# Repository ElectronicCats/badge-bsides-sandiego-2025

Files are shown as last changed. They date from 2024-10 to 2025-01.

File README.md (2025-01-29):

# Badge bsides San Diego 2025

## Technology

- CH32V003
- LEDs
- Display OLED
- 2x AAA Battery Holder
- Shitty Addon Connector

## Gratitude
Do you want to say thank you? Tag these companies on social networks and show them your badge, thanks to them it is possible

- [ElectronicCats](https://electroniccats.com/)
- [BsidesSanDiego](https://www.bsidessd.org/)

## License

Electronic Cats invests time and resources providing this open source design, please support Electronic Cats and open-source hardware by purchasing products from Electronic Cats!

Designed by Electronic Cats.

Hardware released under an CERN Open Hardware Licence v1.2. See the LICENSE_HARDWARE file for more information.

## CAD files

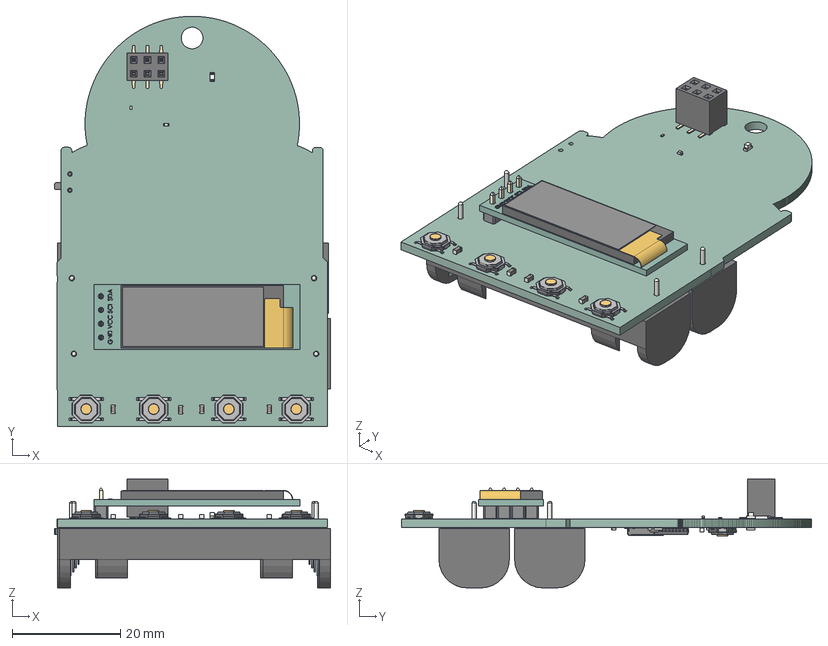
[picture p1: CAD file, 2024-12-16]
hardware/Bsides_sandiego_2025.step
50.9 x 75.7 x 20.1 mm
SW_SPST_TL3342 x 5
PinSocket_2x03_P254mm_Vertical_SMD
C_0603_1608Metric x 6
LED_0201_0603Metric
LED_0402_1005Metric
128x32-OLED v4
LED_0603_1608Metric
R_0603_1608Metric x 8
Keystone_2466_1xAAA x 2
TSSOP_20_44x65mm_P065mm
MSK12C02
_autosave-Bsides_sandiego_2025_PCB

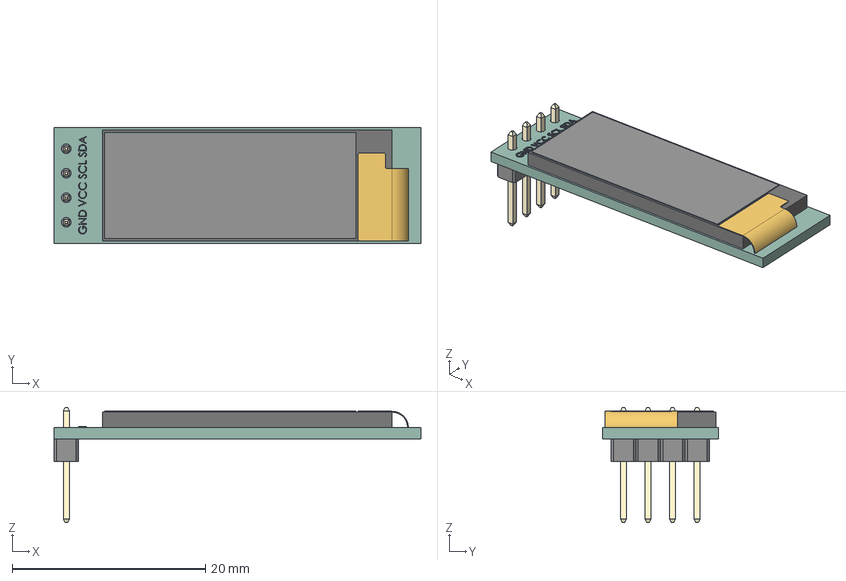
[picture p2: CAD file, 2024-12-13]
hardware/Footprints/3D/128x32-OLED.STEP
38.0 x 12.0 x 11.9 mm

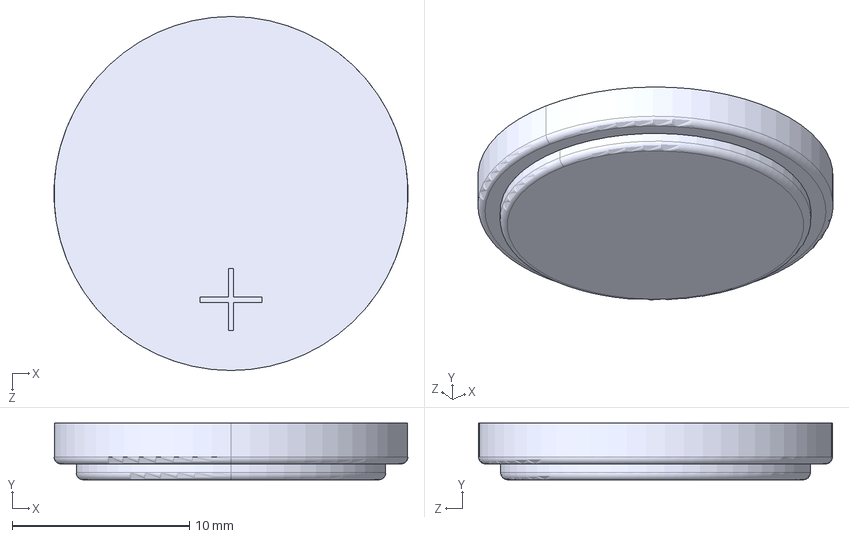
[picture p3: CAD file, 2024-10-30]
hardware/Footprints/3D/CR2032--3DModel-STEP-56544.STEP
20.0 x 3.20 x 20.0 mm

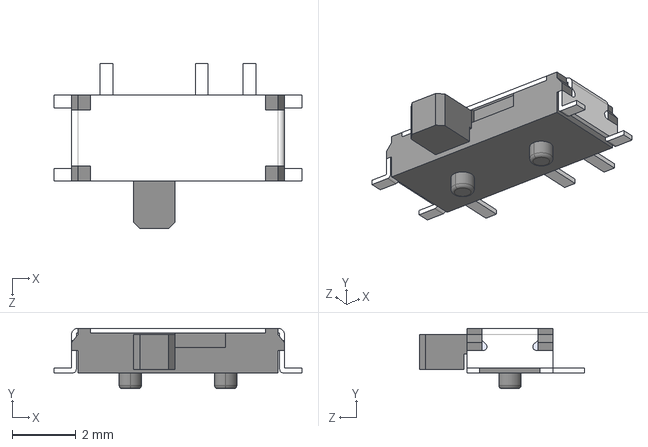
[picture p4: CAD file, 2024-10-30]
hardware/Footprints/3D/MSK12C02.stp
7.80 x 1.90 x 5.20 mm

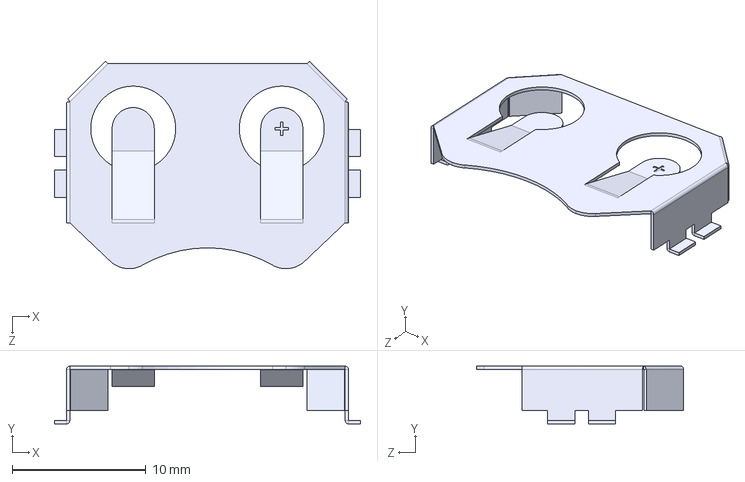
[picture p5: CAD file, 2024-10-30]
hardware/Footprints/3D/BAT-HLD-001--3DModel-STEP-56544.STEP
22.9 x 4.32 x 15.5 mm

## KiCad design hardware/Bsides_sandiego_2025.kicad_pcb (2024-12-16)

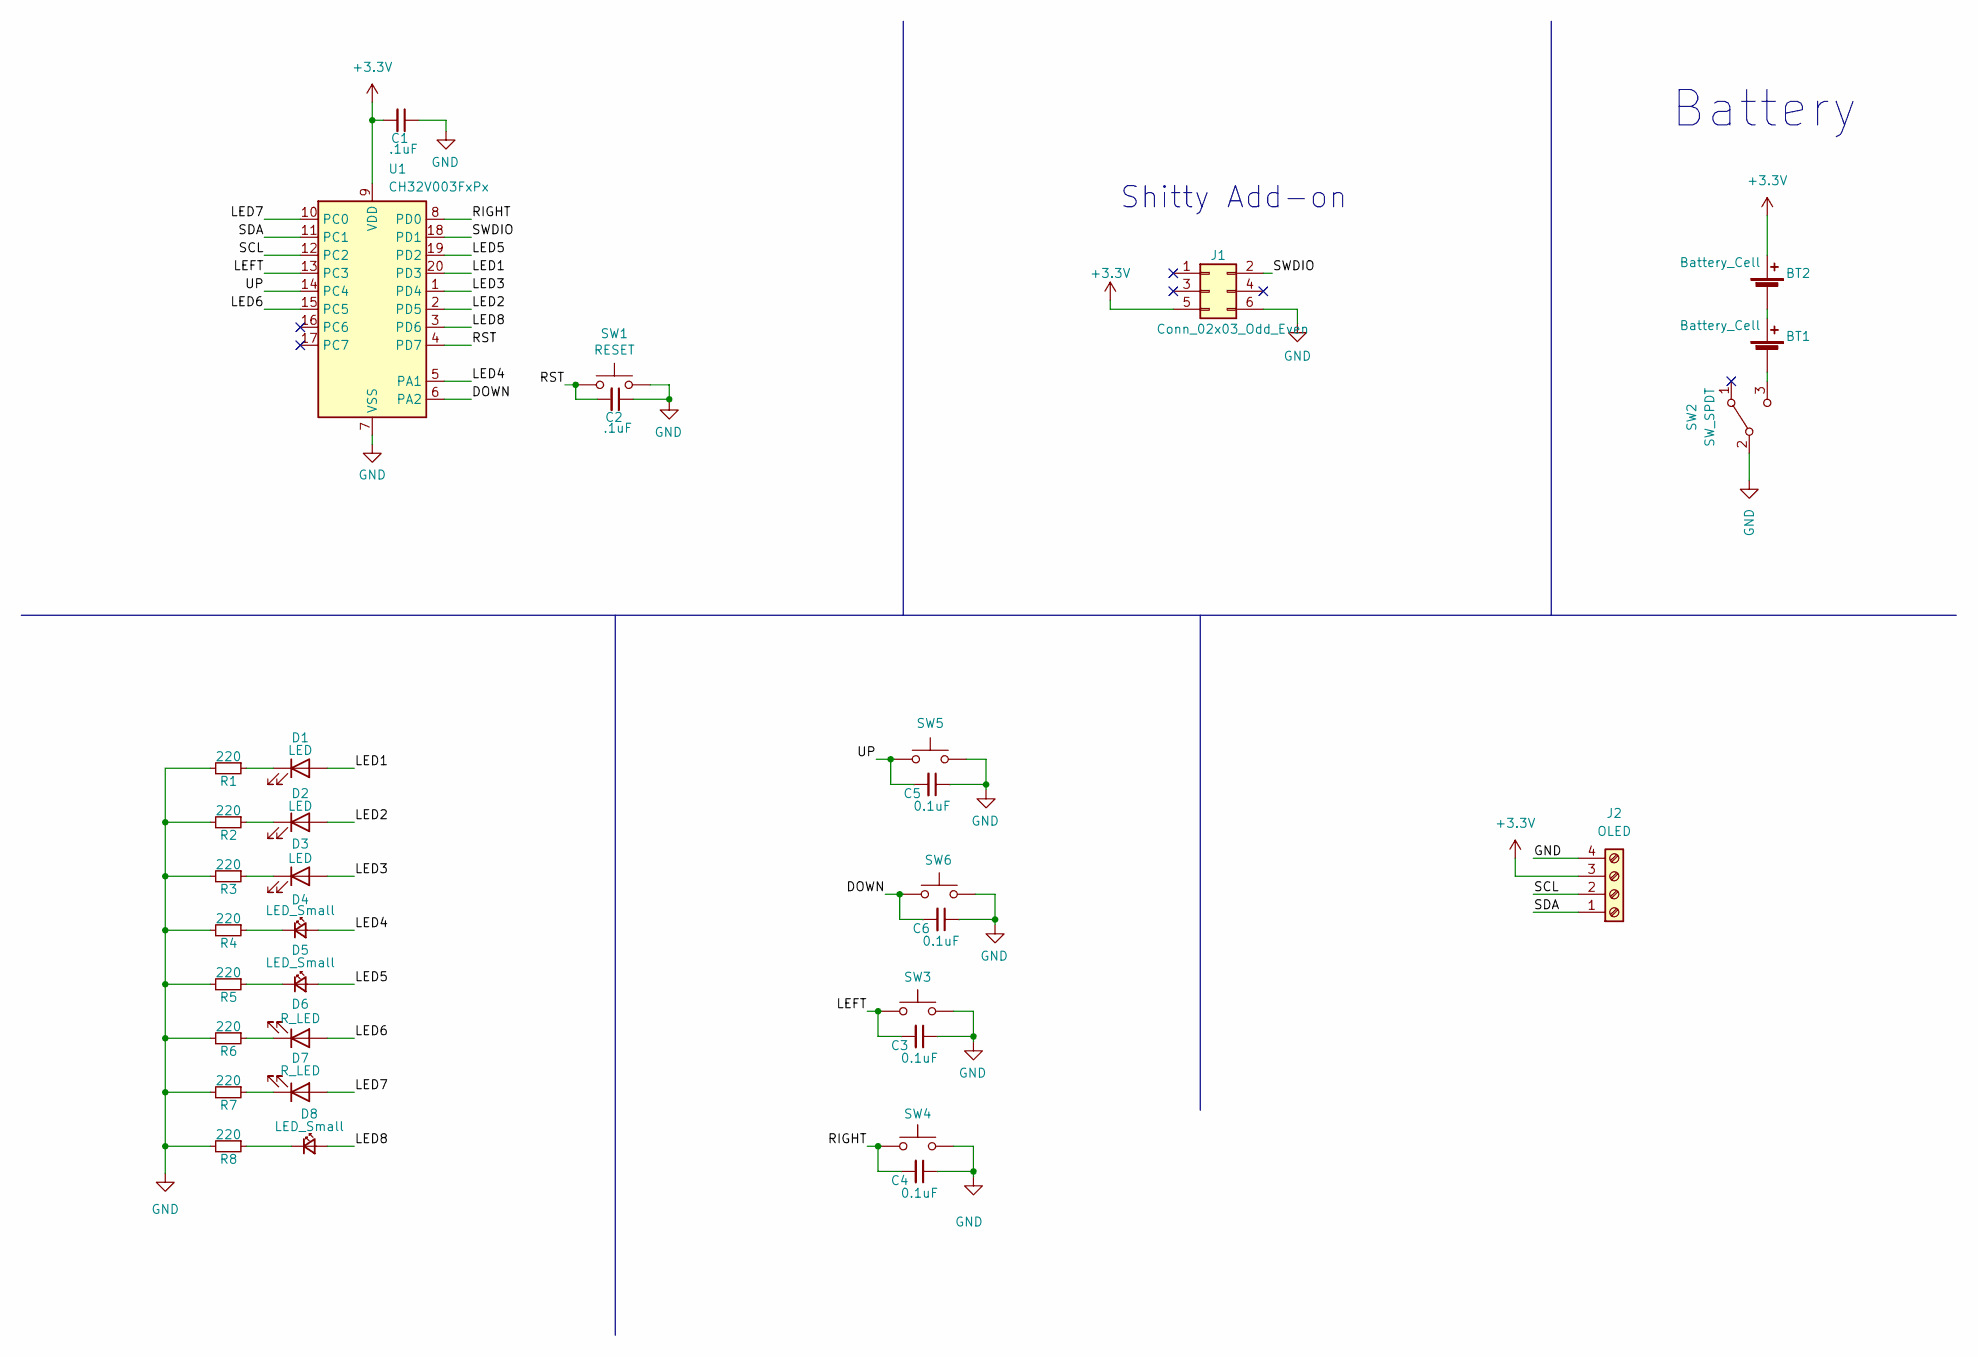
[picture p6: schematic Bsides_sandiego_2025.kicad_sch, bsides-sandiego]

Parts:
BT1, BT2: Battery_Cell; BatteryHolder_Keystone_2466_1xAAA; LCSC# C5290189
C1, C2: .1uF; C_0603_1608Metric; LCSC# C478888
C3, C4, C5, C6: 0.1uF; C_0603_1608Metric; LCSC# C478888
D1: LED; LED_0201_0603Metric; LCSC# C5440628
D2: LED; LED_0402_1005Metric; LCSC# C434450
D3: LED; LED_0603_1608Metric; LCSC# C434424
D4, D5: LED_Small; LED_S; LCSC# C2886268
D6, D7: R_LED; LYT77K-K2M1
D8: LED_Small; Led_S_S; LCSC# C409795
J1: Conn_02x03_Odd_Even; PinHeader_2x03_P2.54mm_Vertical_SMD; LCSC# C124390
J2: OLED; Display OLED 128 x32
R1, R2, R3, R4, R5, R6, R7, R8: 220; R_0603_1608Metric; LCSC# C22962
SW1: RESET; SW_SPST_TL3342; LCSC# C318889
SW2: SW_SPDT; MSK12C02; LCSC# C431540
SW3, SW4, SW5, SW6: SW_SPST_TL3342; LCSC# C318889
U1: CH32V003FxPx; TSSOP-20_4.4x6.5mm_P0.65mm; LCSC# C5187096

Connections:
+3.3V: BT2.2 (+), C1.2, J1.5, J2.3, U1.9 (VDD)
/DOWN: C6.2, SW6.2, U1.6 (PA2)
/LED1: D1.2 (A), U1.20 (PD3)
/LED2: D2.2 (A), U1.2 (PD5)
/LED3: D3.2 (A), U1.1 (PD4)
/LED4: D4.2 (A), U1.5 (PA1)
/LED5: D5.2 (A), U1.19 (PD2)
/LED6: D6.2 (A), U1.15 (PC5)
/LED7: D7.2 (A), U1.10 (PC0)
/LED8: D8.2 (A), U1.3 (PD6)
/LEFT: C3.2, SW3.2, U1.13 (PC3)
/RIGHT: C4.2, SW4.2, U1.8 (PD0)
/RST: C2.2, SW1.2, U1.4 (PD7)
/SCL: J2.2, U1.12 (PC2)
/SDA: J2.1, U1.11 (PC1)
/SWDIO: J1.2, U1.18 (PD1)
/UP: C5.2, SW5.2, U1.14 (PC4)
GND: C1.1, C2.1, C3.1, C4.1, C5.1, C6.1, J1.6, J2.4, R1.2, R2.2, R3.2, R4.2, R5.2, R6.2, R7.2, R8.2, SW1.1, SW2.2 (B), SW3.1, SW4.1, SW5.1, SW6.1, U1.7 (VSS)
unnamed: BT1.2 (+), BT2.1 (-)
unnamed: BT1.1 (-), SW2.3 (C)
unnamed: D1.1 (K), R1.1
unnamed: D2.1 (K), R2.1
unnamed: D3.1 (K), R3.1
unnamed: D4.1 (K), R4.1
unnamed: D5.1 (K), R5.1
unnamed: D6.1 (K), R6.1
unnamed: D7.1 (K), R7.1
unnamed: D8.1 (K), R8.1

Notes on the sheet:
Shitty Add-on
Battery

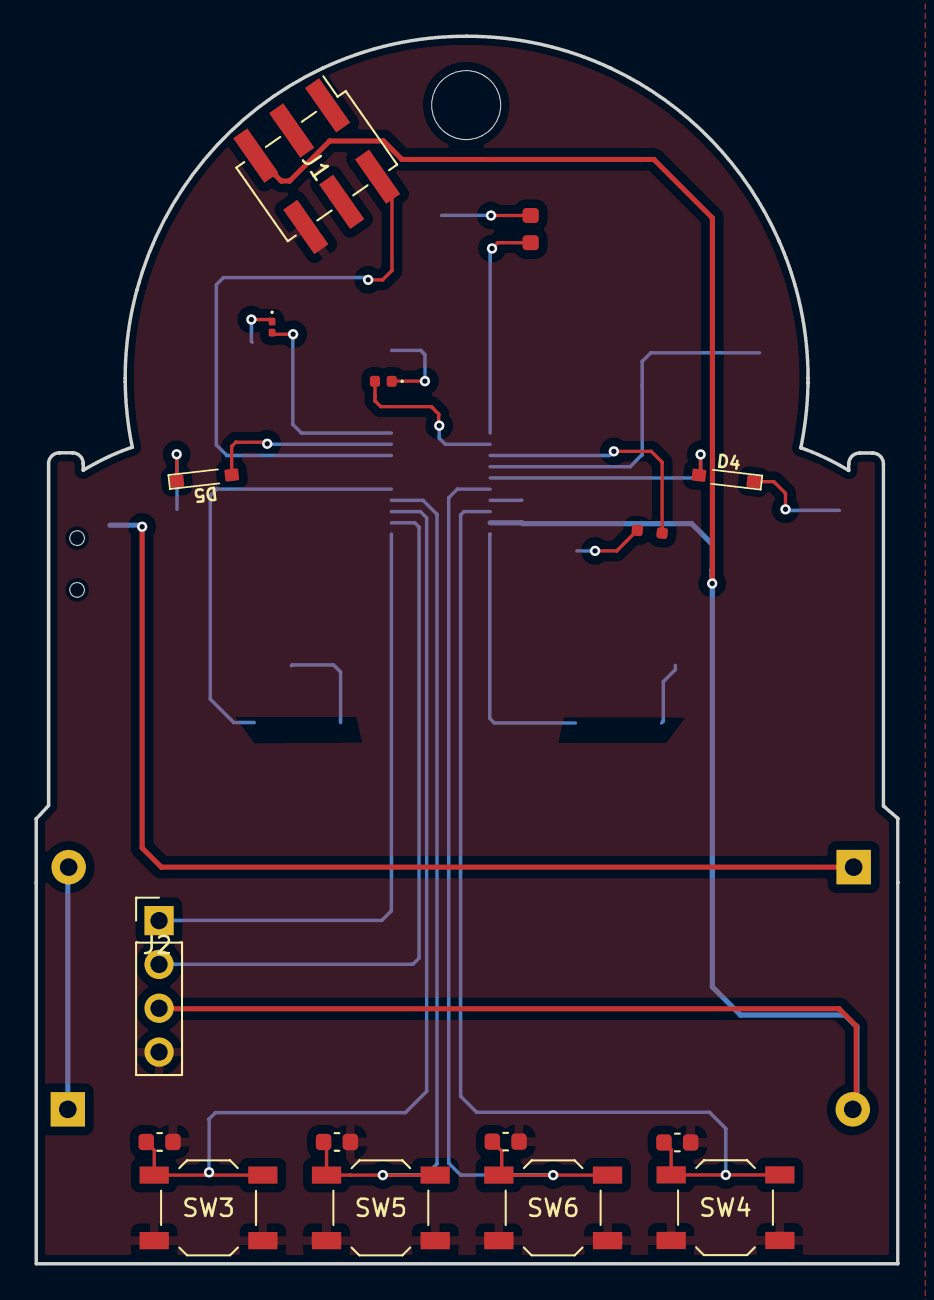
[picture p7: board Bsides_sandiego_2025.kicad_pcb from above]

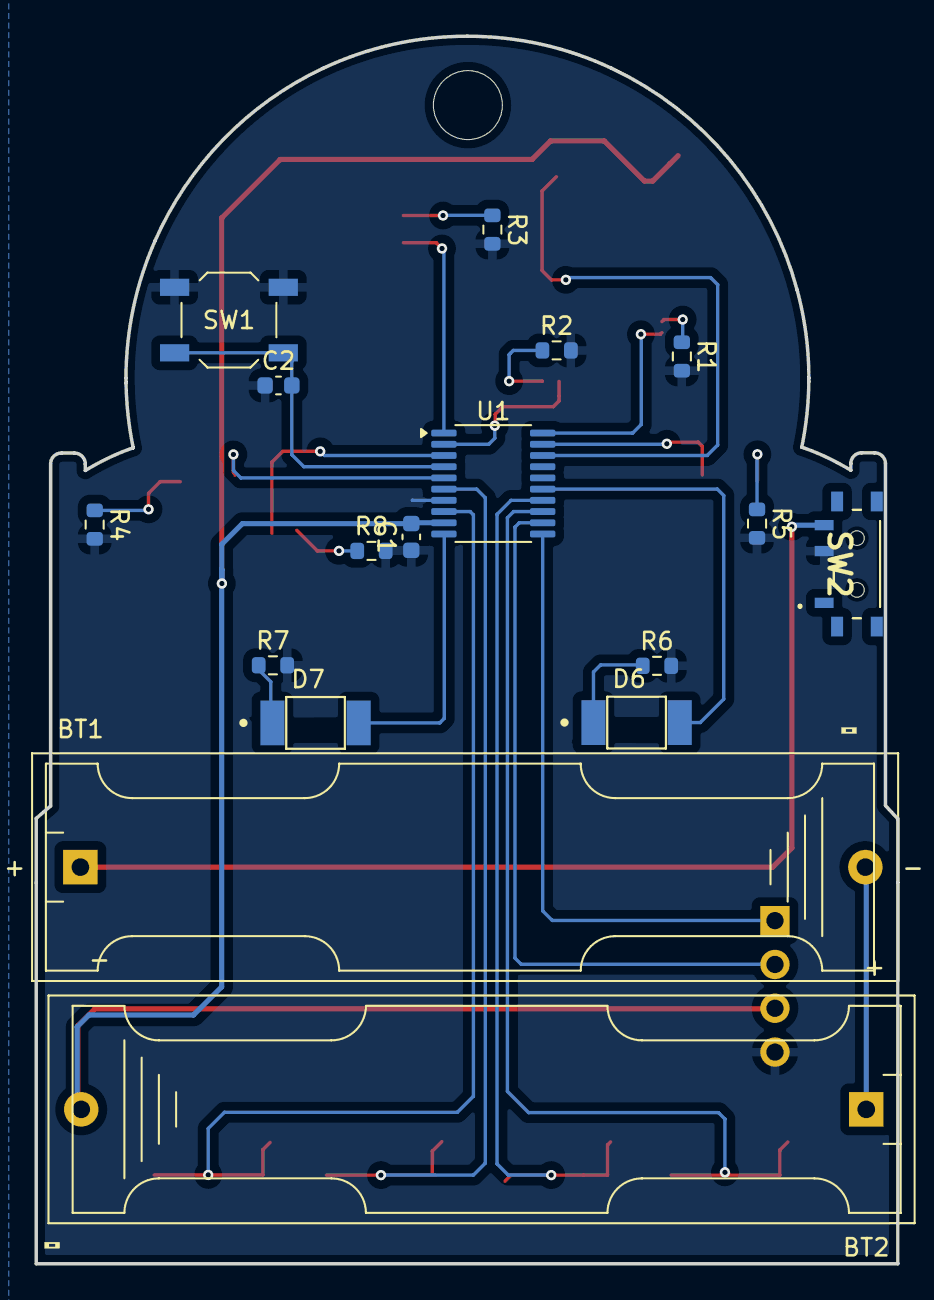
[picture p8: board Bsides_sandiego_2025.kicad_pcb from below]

Board: 2 copper layers, 49.9 x 71.2 mm, 36 parts (19 on the bottom side), 28 nets.

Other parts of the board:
Ref**: Val**; BAGDE BSIDES SAN DIEGO 25_30-10-24
kibuzzard-67607E30, kibuzzard-67607E30#2: G***; kibuzzard-67607E30

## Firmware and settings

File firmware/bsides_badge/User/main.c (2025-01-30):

/********************************** (C) COPYRIGHT
 ******************************** File Name          : main.c Author : WCH
 * Version            : V1.0.0
 * Date               : 2023/12/25
 * Description        : Main program body.
 *********************************************************************************
 * Copyright (c) 2021 Nanjing Qinheng Microelectronics Co., Ltd.
 * Attention: This software (modified or not) and binary are used for
 * microcontroller manufactured by Nanjing Qinheng Microelectronics.
 *******************************************************************************/

/*
 *@Note
 *Multiprocessor communication mode routine:
 *Master:USART1_Tx(PD5)\USART1_Rx(PD6).
 *This routine demonstrates that USART1 receives the data sent by CH341 and
 *inverts it and sends it (baud rate 115200).
 *
 *Hardware connection:PD5 -- Rx
 *                     PD6 -- Tx
 *
 */

#include <limits.h>
#include "../SSD1306/include/ssd1306.h"
#include "bitmaps.h"
#include "debug.h"
#include "driver.h"
#include "hardware_tests.h"
#include "menus.h"
#include "tetris.h"

uint16_t valueInFlash;

void USARTx_CFG(void);

int main() {
  SystemCoreClockUpdate();
  Delay_Init();
#if (SDI_PRINT == SDI_PR_OPEN)
  SDI_Printf_Enable();
#else
  USART_Printf_Init(115200);
#endif

  // Setup
  // USARTx_CFG();
  JOY_init();
  ssd1306_setbuf(0);
  ssd1306_refresh();
  ssd1306_drawImage(epd_bitmap_bsides_logo, 0, 0, 128, 32, COLOR_NORMAL);
  ssd1306_refresh();

  // Blink all the LEDs
  uint8_t delay = 50;
  for (uint8_t i = 0; i < leds_count; i++) {
    PIN_high(leds[i]);
    JOY_DLY_ms(delay);
    PIN_low(leds[i]);
    JOY_DLY_ms(delay);
  }
  Delay_Ms(500);  // Keep the logo on the screen for a while
  // flash_test();
  // hardware_tests_start();
  menus_init();
  // tetris_start();
}

/*********************************************************************
 * @fn      USARTx_CFG
 *
 * @brief   Initializes the USART2 & USART3 peripheral.
 *
 * @return  none
 */
void USARTx_CFG(void) {
  GPIO_InitTypeDef GPIO_InitStructure = {0};
  USART_InitTypeDef USART_InitStructure = {0};

  RCC_APB2PeriphClockCmd(RCC_APB2Periph_GPIOD | RCC_APB2Periph_USART1, ENABLE);

  /* USART1 TX-->D.5   RX-->D.6 */
  GPIO_InitStructure.GPIO_Pin = GPIO_Pin_5;
  GPIO_InitStructure.GPIO_Speed = GPIO_Speed_30MHz;
  GPIO_InitStructure.GPIO_Mode = GPIO_Mode_AF_PP;
  GPIO_Init(GPIOD, &GPIO_InitStructure);
  GPIO_InitStructure.GPIO_Pin = GPIO_Pin_6;
  GPIO_InitStructure.GPIO_Mode = GPIO_Mode_IN_FLOATING;
  GPIO_Init(GPIOD, &GPIO_InitStructure);

  USART_InitStructure.USART_BaudRate = 115200;
  USART_InitStructure.USART_WordLength = USART_WordLength_8b;
  USART_InitStructure.USART_StopBits = USART_StopBits_1;
  USART_InitStructure.USART_Parity = USART_Parity_No;
  USART_InitStructure.USART_HardwareFlowControl =
      USART_HardwareFlowControl_None;
  USART_InitStructure.USART_Mode = USART_Mode_Tx | USART_Mode_Rx;

  USART_Init(USART1, &USART_InitStructure);
  USART_Cmd(USART1, ENABLE);
}

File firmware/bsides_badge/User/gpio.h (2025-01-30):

// ===================================================================================
// Basic GPIO Functions for CH32V003                                          * v1.6 *
// ===================================================================================
//
// Pins must be defined as PA0, PA1, .., PC0, PC1, etc. - e.g.:
// #define PIN_LED PC0      // LED on pin PC0
//
// PIN functions available:
// ------------------------
// PIN_input(PIN)           Set PIN as INPUT (floating, no pullup/pulldown)
// PIN_input_PU(PIN)        Set PIN as INPUT with internal PULLUP resistor
// PIN_input_PD(PIN)        Set PIN as INPUT with internal PULLDOWN resistor
// PIN_input_AN(PIN)        Set PIN as INPUT for analog peripherals (e.g. ADC) (*)
// PIN_output(PIN)          Set PIN as OUTPUT (push-pull)
// PIN_output_OD(PIN)       Set PIN as OUTPUT (open-drain)
// PIN_alternate(PIN)       Set PIN as alternate output (push-pull)
// PIN_alternate_OD(PIN)    Set PIN as alternate output (open-drain)
//
// PIN_low(PIN)             Set PIN output value to LOW (*)
// PIN_high(PIN)            Set PIN output value to HIGH
// PIN_toggle(PIN)          TOGGLE PIN output value
// PIN_read(PIN)            Read PIN input value
// PIN_write(PIN, val)      Write PIN output value (0 = LOW / 1 = HIGH)
//
// PIN interrupt and event functions available:
// --------------------------------------------
// PIN_EVT_set(PIN,TYPE)    Setup PIN event TYPE:
//                          PIN_EVT_OFF, PIN_EVT_RISING, PIN_EVT_FALLING, PIN_EVT_BOTH
// PIN_INT_set(PIN,TYPE)    Setup PIN interrupt TYPE:
//                          PIN_INT_OFF, PIN_INT_RISING, PIN_INT_FALLING, PIN_INT_BOTH
// PIN_INT_enable()         Enable PIN interrupts
// PIN_INT_disable()        Disable PIN interrupts
// PIN_INTFLAG_read(PIN)    Read interrupt flag of PIN
// PIN_INTFLAG_clear(PIN)   Clear interrupt flag of PIN
// PIN_INT_ISR { }          Pin interrupt service routine
//
// PORT functions available:
// -------------------------
// PORT_enable(PIN)         Enable GPIO PORT of PIN
// PORTA_enable()           Enable GPIO PORT A
// PORTC_enable()           Enable GPIO PORT C
// PORTD_enable()           Enable GPIO PORT D
// PORTS_enable()           Enable all GPIO PORTS
//
// PORT_disable(PIN)        Disable GPIO PORT of PIN
// PORTA_disable()          Disable GPIO PORT A
// PORTC_disable()          Disable GPIO PORT C
// PORTD_disable()          Disable GPIO PORT D
// PORTS_disable()          Disable all GPIO PORTS
//
// Analog-to-Digital Converter (ADC) functions available:
// ------------------------------------------------------
// ADC_init()               Init, enable and calibrate ADC (must be called first)
// ADC_enable()             Enable ADC (power-up)
// ADC_disable()            Disable ADC (power-down)
// ADC_calibrate()          Calibrate ADC
//
// ADC_fast()               Set fast mode   ( 28 clock cycles, least accurate) (*)
// ADC_medium()             Set medium mode (168 clock cycles, medium accurate)
// ADC_slow()               Set slow mode   (504 clock cycles, most accurate)
//
// ADC_input(PIN)           Set PIN as ADC input
// ADC_input_VREF()         Set internal voltage referece (Vref) as ADC input
// ADC_input_VCAL()         Set calibration voltage (Vcal) as ADC input
//
// ADC_read()               Sample and read ADC value (0..1023)
// ADC_read_VDD()           Sample and read supply voltage (VDD) in millivolts (mV)
//
// Op-Amp Comparator (OPA) functions available:
// --------------------------------------------
// OPA_enable()             Enable OPA comparator
// OPA_disable()            Disable OPA comparator
// OPA_negative(PIN)        Set OPA inverting input PIN (PA1, PD0 only)
// OPA_positive(PIN)        Set OPA non-inverting input PIN (PA2, PD7 only)
// OPA_output()             Enable OPA output (push-pull) on pin PD4
// OPA_output_OD()          Enable OPA output (open-drain) on pin PD4
// OPA_read()               Read OPA output (0: pos < neg, 1: pos > neg)
//
// Notes:
// ------
// - (*) default state
// - For interrupts and events: Each PIN number can only be used once simultaneously.
//   (For example, PA1 and PC1 cannot be used simultaneously, but PA1 and PC2).
// - Pins used for ADC must be set with PIN_input_AN beforehand. Only the following 
//   pins can be used as INPUT for the ADC: PA1, PA2, PC4, PD2, PD3, PD4, PD5, PD6.
// - Pins used as input for OPA comparator must be set with PIN_input_AN beforehand.
//   Only the following pins can be used for the OPA: PA1 or PD0 as negative
//   (inverting) input, PA2 or PD7 as positive (non-inverting) input and PD4 as
//   ouput.
//
// 2023 by Stefan Wagner:   https://github.com/wagiminator

#pragma once

#ifdef __cplusplus
extern "C" {
#endif
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

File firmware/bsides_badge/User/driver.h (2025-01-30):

// ===================================================================================
// Tiny Joypad Drivers for CH32V003                                           *
// v1.0 *
// ===================================================================================
//
// MCU abstraction layer.
// 2023 by Stefan Wagner:   https://github.com/wagiminator

#pragma once

#ifdef __cplusplus
extern "C" {
#endif

#include <stdbool.h>
#include "ch32v00x.h"
#include "gpio.h"
#include "oled_min.h"

// #define DEBUG_ENABLE 1
// #define DEV_VERSION 1

#define APP_DBG(X...)             \
  if (1) {                        \
    PRINT("[%s] ", __FUNCTION__); \
    PRINT(X);                     \
    PRINT("\r\n");                \
  }

// Pin assignments
#define BUTTON_RIGHT_PIN PD0
#define BUTTON_LEFT_PIN  PC3
#define BUTTON_UP_PIN    PC4
#ifdef DEV_VERSION
  #define BUTTON_DOWN_PIN PC6
#else
  #define BUTTON_DOWN_PIN PA2
#endif

#define LED1_PIN PD3
#define LED2_PIN PD5
#define LED3_PIN PD4
#define LED4_PIN PA1
#define LED5_PIN PD2
#define LED6_PIN PC5
#define LED7_PIN PC0
#define LED8_PIN PD6

#define PIN_SCL PC2  // pin connected to OLED (I2C SCL)
#define PIN_SDA PC1  // pin connected to OLED (I2C SDA)

// Delays
#define JOY_DLY_ms Delay_Ms
#define JOY_DLY_us Delay_Us

// Additional Defines
#define abs(n) ((n >= 0) ? (n) : (-(n)))

// Game slow-down delay
#define JOY_SLOWDOWN()  // DLY_ms(10)

extern uint8_t leds[];
extern uint8_t leds_count;

#define JOY_pad_pressed()  (ADC_read() > 10)
#define JOY_pad_released() (ADC_read() <= 10)

// static inline void JOY_init(void);
void JOY_init(void);

// OLED commands
#define JOY_OLED_init            OLED_init
#define JOY_OLED_end             I2C_stop
#define JOY_OLED_send(b)         I2C_write(b)
#define JOY_OLED_send_command(c) OLED_send_command(c)
#define JOY_OLED_data_start(y) \
  {                            \
    OLED_setpos(0, y);         \
    OLED_data_start();         \
  }

// Buttons
#define JOY_pad_pressed()  (ADC_read() > 10)
#define JOY_pad_released() (ADC_read() <= 10)

uint8_t joy_up_pressed(void);
uint8_t joy_down_pressed(void);
uint8_t joy_left_pressed(void);
uint8_t joy_right_pressed(void);
uint16_t JOY_random(void);
long map(long x, long in_min, long in_max, long out_min, long out_max);

#ifdef __cplusplus
};
#endif

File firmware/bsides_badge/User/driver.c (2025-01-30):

#include "driver.h"

uint8_t leds[] = {LED1_PIN,
#ifndef DEBUG_ENABLE
                  LED2_PIN,
#endif
                  LED3_PIN, LED4_PIN, LED5_PIN, LED6_PIN, LED7_PIN, LED8_PIN};
uint8_t leds_count = sizeof(leds) / sizeof(leds[0]);

// Init driver
void JOY_init(void) {
  // Enable GPIO Ports
  PORTS_enable();

  // Set LED pins as output
  PIN_output(LED1_PIN);
#ifndef DEBUG_ENABLE
  PIN_output(LED2_PIN);
#endif
  PIN_output(LED3_PIN);
  PIN_output(LED4_PIN);
  PIN_output(LED5_PIN);
  PIN_output(LED6_PIN);
  PIN_output(LED7_PIN);
  PIN_output(LED8_PIN);

  GPIO_InitTypeDef GPIO_InitStruct;
  RCC_APB2PeriphClockCmd(RCC_APB2Periph_GPIOC, ENABLE);
  GPIO_InitStruct.GPIO_Mode = GPIO_Mode_IPU;
#ifndef DEV_VERSION
  GPIO_InitStruct.GPIO_Pin = GPIO_Pin_3 | GPIO_Pin_4 | GPIO_Pin_6;
#else
  GPIO_InitStruct.GPIO_Pin = GPIO_Pin_3 | GPIO_Pin_4;
#endif
  GPIO_InitStruct.GPIO_Speed = GPIO_Speed_30MHz;
  GPIO_Init(GPIOC, &GPIO_InitStruct);

  GPIO_InitStruct.GPIO_Mode = GPIO_Mode_IPU;
  GPIO_InitStruct.GPIO_Pin = GPIO_Pin_0;
  GPIO_InitStruct.GPIO_Speed = GPIO_Speed_30MHz;
  GPIO_Init(GPIOD, &GPIO_InitStruct);

#ifndef DEV_VERSION
  GPIO_PinRemapConfig(GPIO_Remap_PA1_2, DISABLE);
  GPIO_InitStruct.GPIO_Mode = GPIO_Mode_IPU;
  GPIO_InitStruct.GPIO_Pin = GPIO_Pin_2;
  GPIO_InitStruct.GPIO_Speed = GPIO_Speed_30MHz;
  GPIO_Init(GPIOA, &GPIO_InitStruct);
#endif

  OLED_init();
}

uint8_t joy_up_pressed(void) {
  return !PIN_read(BUTTON_UP_PIN);
}

uint8_t joy_down_pressed(void) {
  return !PIN_read(BUTTON_DOWN_PIN);
}

uint8_t joy_left_pressed(void) {
  return !PIN_read(BUTTON_LEFT_PIN);
}

uint8_t joy_right_pressed(void) {
  return !PIN_read(BUTTON_RIGHT_PIN);
}

// Pseudo random number generator
uint16_t rnval = 0xACE1;
uint16_t JOY_random(void) {
  rnval = (rnval >> 0x01) ^ (-(rnval & 0x01) & 0xB400);
  return rnval;
}

long map(long x, long in_min, long in_max, long out_min, long out_max) {
  return (x - in_min) * (out_max - out_min) / (in_max - in_min) + out_min;
}

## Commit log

2025-01-13 feat: remap buttons
2025-01-14 fix: gpio pins initialization
    [driver.h]
2025-01-14 feat: add leds animation at startup
2025-01-16 feat: save reboot counter on flash
    [main.c]
2025-01-22 fix: pa port init
    [driver.c, driver.h, main.c]
2025-01-24 feat: reduce buttons sensibilitiy on game
2025-01-24 fix: repeated clicks while inserting nickname
2025-01-28 feat: change nickname menu by leds menu icon
2025-01-28 feat: add leds control
2025-01-29 fix: reduce buttons sensibilty
2025-01-29 feat: turn leds off inside menus
